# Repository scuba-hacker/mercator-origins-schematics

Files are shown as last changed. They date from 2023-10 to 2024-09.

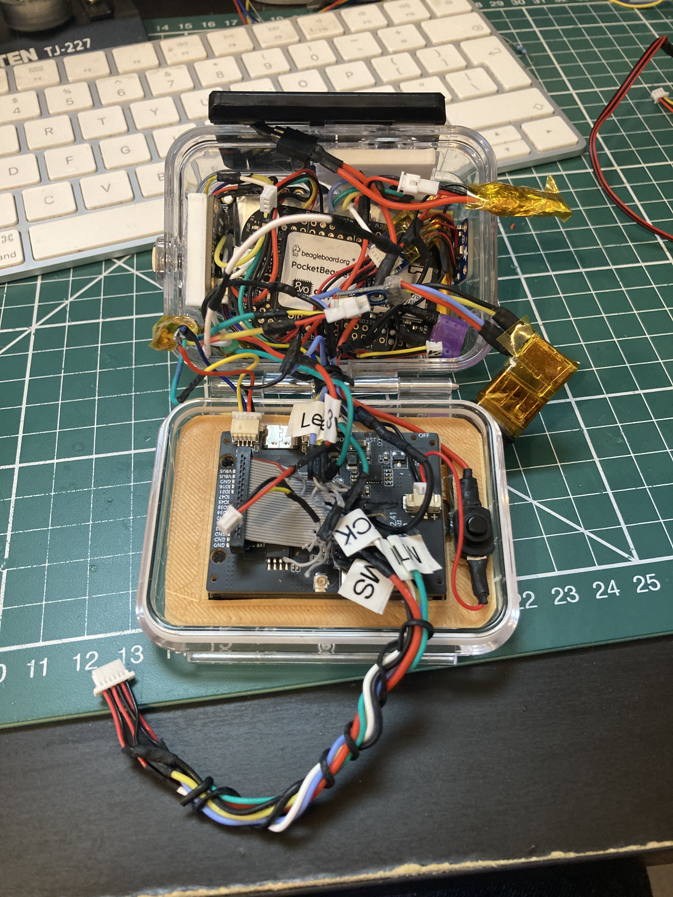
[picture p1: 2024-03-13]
Kicad/Oceanic/beagle and oceanic.jpg

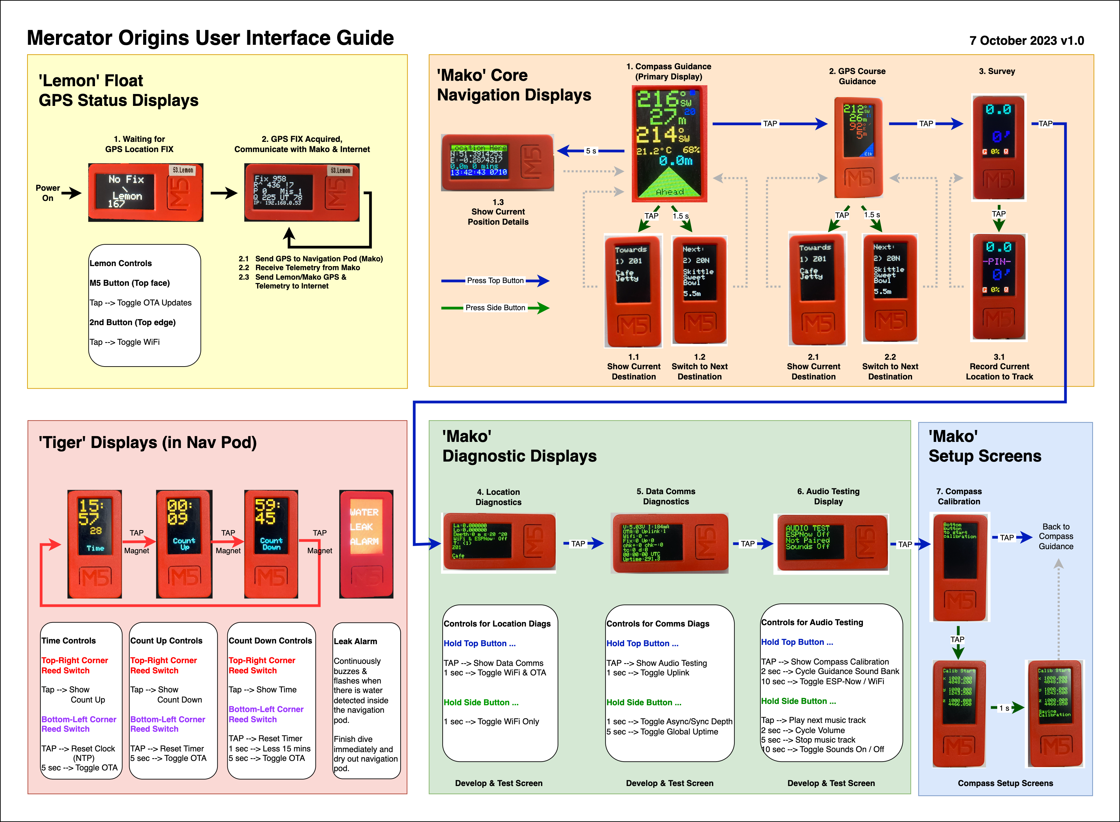
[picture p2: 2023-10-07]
DrawIO_Diagrams/Mercator Origins Displays and Controls.png

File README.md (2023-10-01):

# mercator-origins-schematics

3D Print files for button mounts. To follow: Console and Float schematics for drilling holes and sensor placement. Wiring harness schematics too.

GoPro_Side_Mount_image

Go_Pro_Top_Button_Mount_image

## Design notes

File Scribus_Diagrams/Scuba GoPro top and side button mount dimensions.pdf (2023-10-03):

# Top Button Mount, Top View

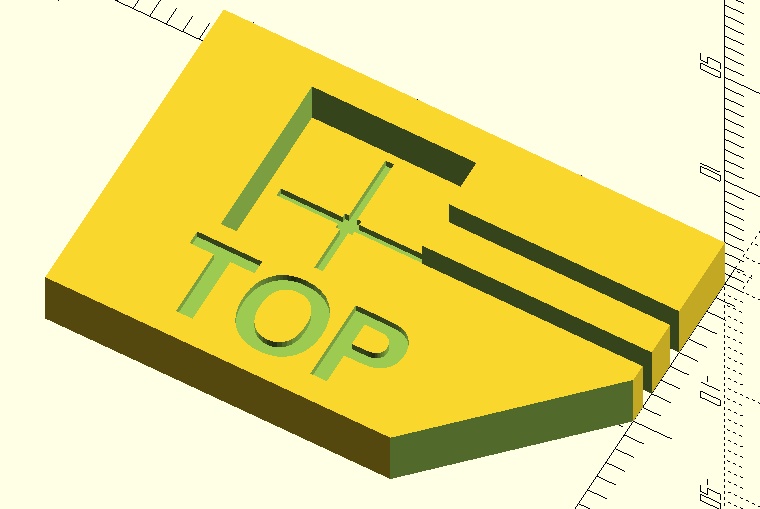
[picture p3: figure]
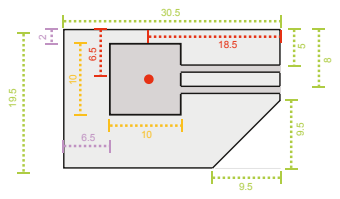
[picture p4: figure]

* All dimensions in millimetres.
* 3D print renders for illustration only.
* Light gray areas are 4mm thick.
* Dark gray areas are 1mm thick (bottom of mount)
* Wire channels are 1mm wide.
* Red spot is where to centre the microswitch button.

# Side Button Mount, Top View

Suggested build without 3D printer is to use a glued sandwich of two plastic window shims as follows:

1. Cut a 1mm thick shim to the overall outline of the mount and mark the centre point for the microswitch, with no internal cuts.
2. Cut a 3mm thick shim as per all cuts shown in the schematic omit the wire

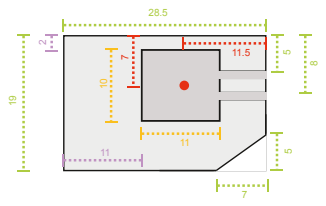
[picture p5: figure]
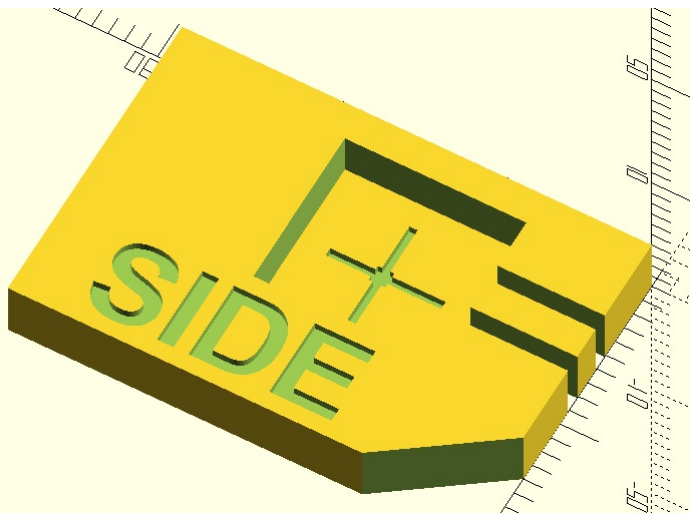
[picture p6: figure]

channel separator if you want. The cutout surrounding the microswitch just needs to be large enough to prevent the press button plunger from hitting edge of the cutout. Alternative to cutting is drilling a 10mm hole.

3. Glue the 1mm shim to the bottom of the 3mm shim.
4. Solder wires to your microswitch and glue the microswitch so that the button is positioned over the marked spot. Feed the wires out of the right side of the mount and glue wires to complete the build.

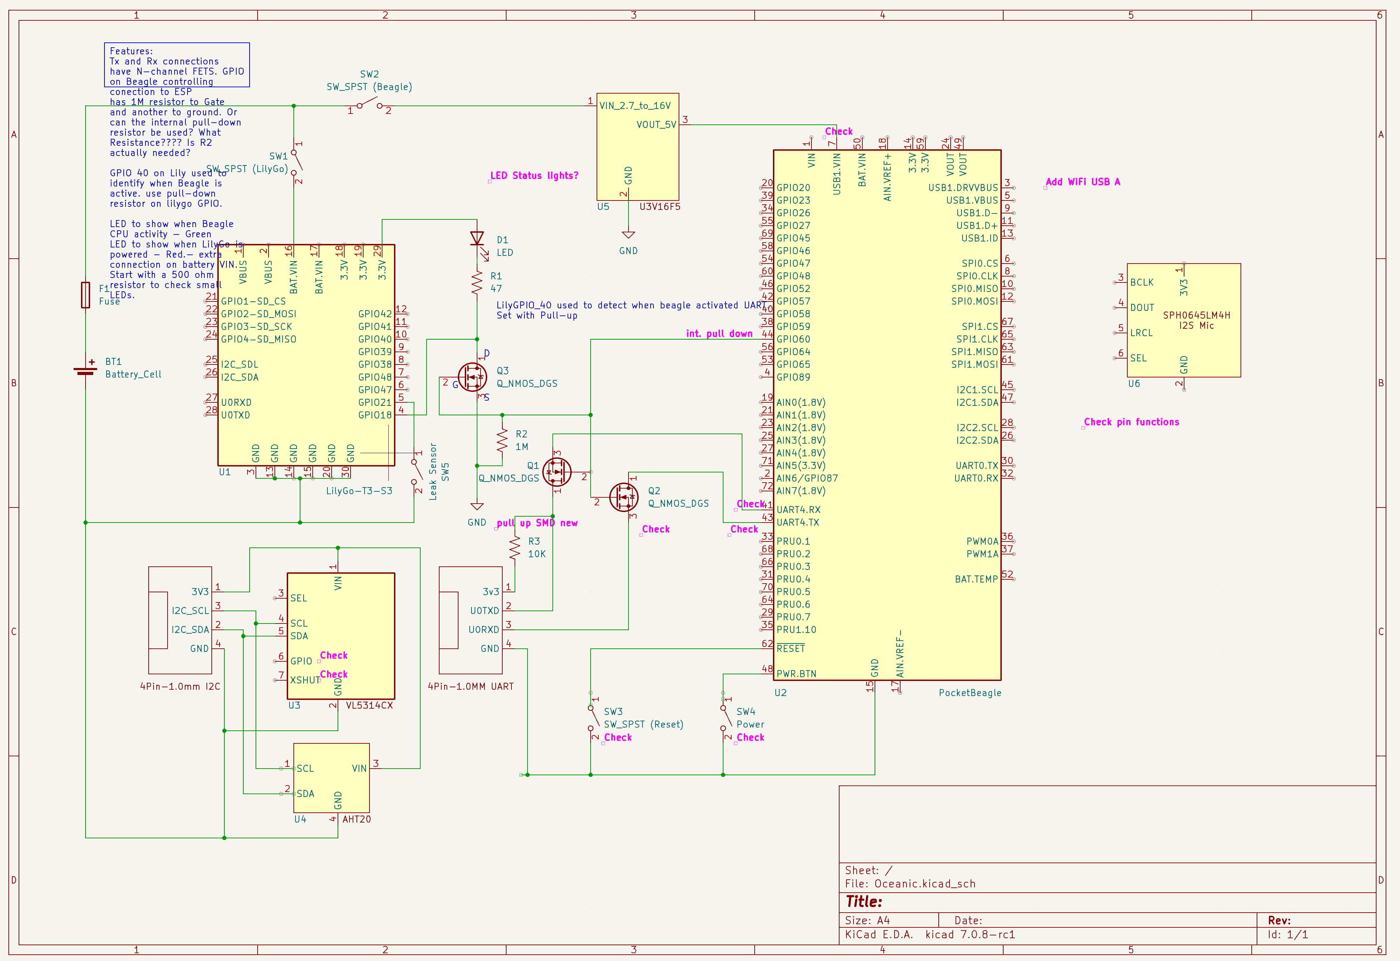
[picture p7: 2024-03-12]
Kicad/Oceanic/2024-03-12 1920 Oceanic Schematic Snapshot .png

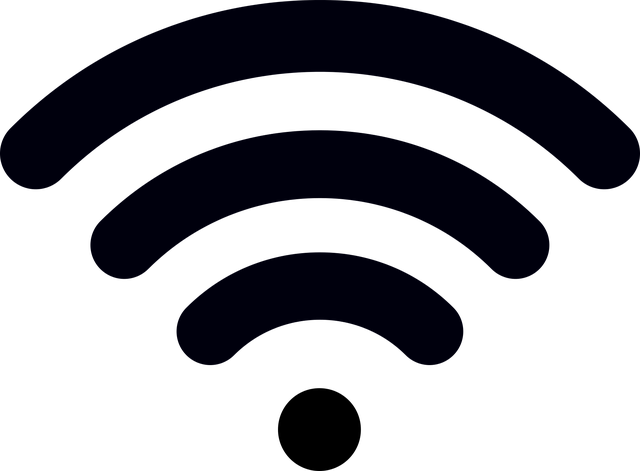
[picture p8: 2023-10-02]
Kicad/Audio-Pod-2/Images/wi-fi-2119225_640.png

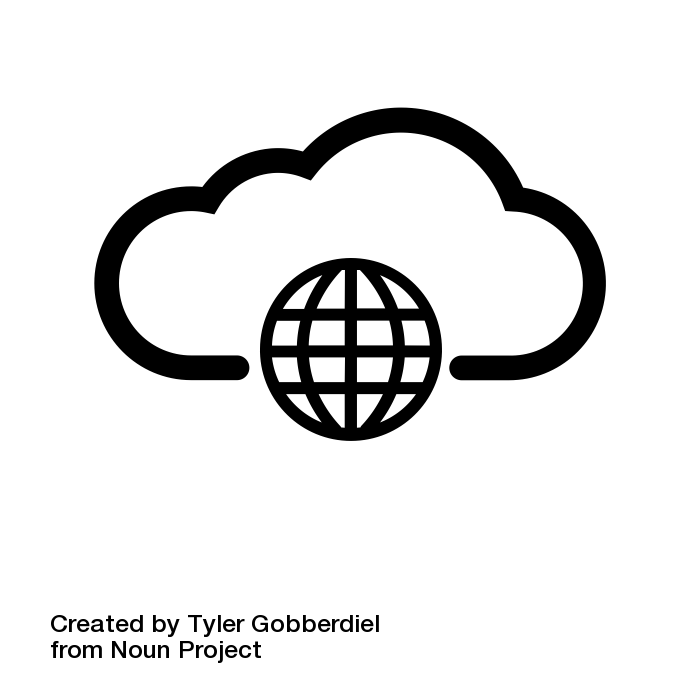
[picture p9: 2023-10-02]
Kicad/Lemon-GPS-Float/Images/noun-cloud-network-4059258.png

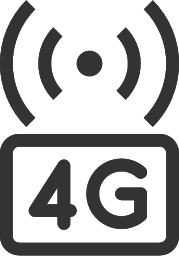
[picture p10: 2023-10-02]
Kicad/Lemon-GPS-Float/Images/4g.179x256.png

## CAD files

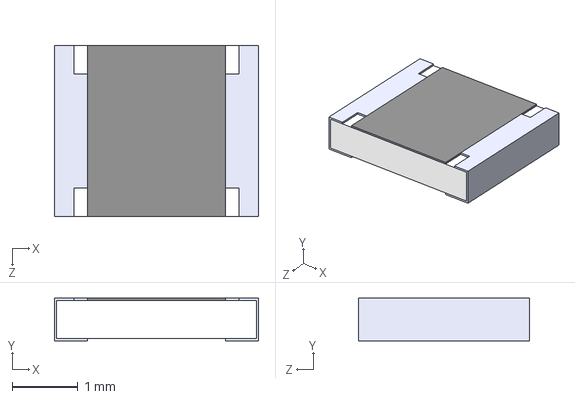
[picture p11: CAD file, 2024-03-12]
Kicad/Oceanic/KiCad Symbols/CRGCQ1210J1M0/CRGCQ1210J1M0.step
3.10 x 0.65 x 2.60 mm

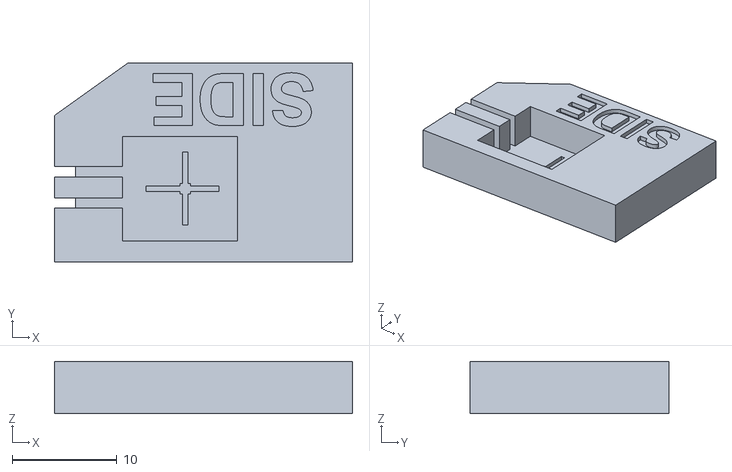
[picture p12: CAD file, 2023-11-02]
SCAD_3d_print/GoPro_Side_Mount.stl
28.5 x 19.0 x 5.00

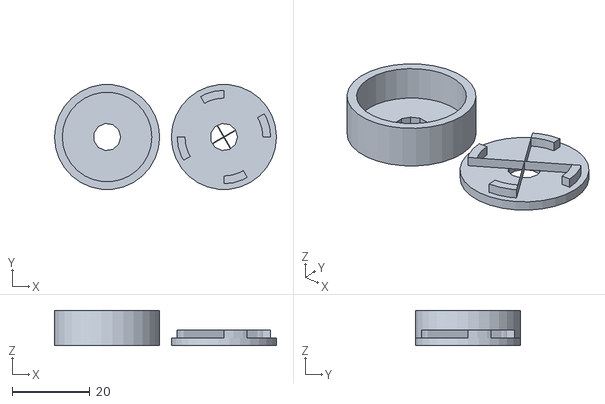
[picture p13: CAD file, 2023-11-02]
Torch Battery Shunt/torch_battery_shunt.stl
57.0 x 26.9 x 9.10

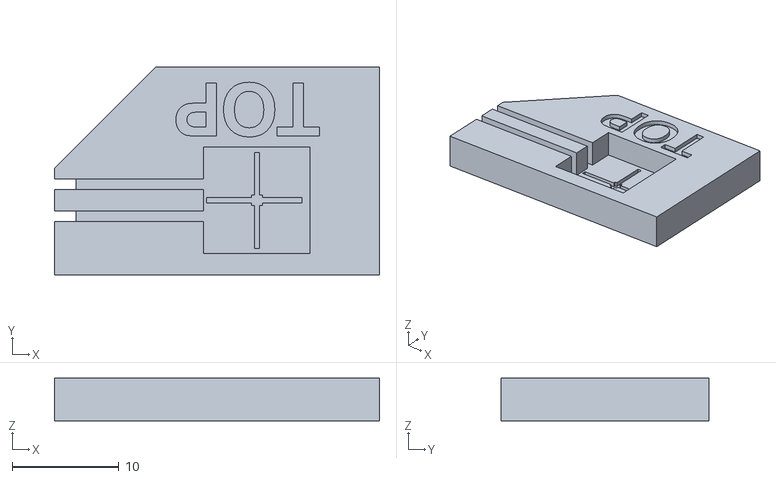
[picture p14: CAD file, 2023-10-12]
SCAD_3d_print/GoPro_Top_Button_Mount.stl
30.5 x 19.5 x 4.00

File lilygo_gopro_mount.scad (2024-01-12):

#include <BOSL2/std.scad>

$fs = 1;

// edge descriptors
// https://github.com/BelfrySCAD/BOSL2/wiki/attachments.scad#subsection-specifying-directions

interior_l = 73.8;
interior_w = 52.5;
interior_h = 6.2; // 6.2
interior_radius = 9;

med_l = 78.1;
med_w = 56.8;
med_h = 4.95;
med_radius = 11;

outer_l = 83.6;
outer_w = 61.6;
outer_h = 5.9;

outer_radius=13;

//insert_l = interior_l + 0.5;    // made .5mm longer than aperature      // ACTUAL PRINT WIDTH = 53.5 instead of 53 (correction is -0.5)
//insert_w = interior_w + 0.5;    // made .5mm wider than aperature       // ACTUAL PRINT LENGTH = 74.75 instead of 74.3 (correction is -0.45)

insert_l = interior_l + -0.5;    // corrected for next print 16 Jan (make exact interior length)
insert_w = interior_w + -0.45;   // corrected for next print 16 Jan (make exact interior width)


// 11/01 New measured cut width of insert: (needs removing from gopro case)
// 11/01  New measured cut length of insert: (needs removing from gopro case)

insert_h = 1.5;

screen_l = 56.2;   // measure       (11/01 measured again to be 56.2)   (11/01 measured inner ridge frame 55.73mm length)
screen_w = 43.9;   // measure       (11/01 measured again to be 43.9)   (11/01 measured inner ridth frame 43.35mm width)
screen_h = 1;

// screen has 3mm overlap on header short edge (currently 1.7mm), and 2mm overlap on lcd flex short edge (currently 1.85mm)
//screen has 2.35mm  overlap on antenna long edge and 2.7mm overlap on usb long edge


ridge_thickness = 1;

pcb_l = 52;
pcb_w = 39.2;
pcb_h = 1;

inner_shell_thickness = (med_l-interior_l)/2;

// insert

z_offset = 50;      // keeps the insert away from the gopro case in the view

ridge_pcb_cut_out_l = ridge_thickness*2;
ridge_pcb_cut_out_w = 22;
ridge_pcb_cut_out_h = insert_h;

ridge_pcb_cut_out_offset_w = 5.2;

ridge_usb_cut_out_l = 24;
ridge_usb_cut_out_w = ridge_thickness*2;
ridge_usb_cut_out_h = insert_h;

ridge_usb_cut_out_offset_l = 50 - ridge_usb_cut_out_l;

    
difference()
{
    difference()
    {
        // Insert to back screen, hole is sized to fit pcb attached to screen
        difference()       // (larger piece - smaller piece)
        {
            // the actual insert (square ring) that will be nanotaped down
            translate([0,0,z_offset])
                cuboid(
                    [insert_l,insert_w,insert_h], rounding=9,
                    edges=[RIGHT+BACK, RIGHT+FRONT, LEFT+BACK,LEFT+FRONT],
                    $fn=30,anchor=[-1,-1,-1]);
            
            // the hole in the insert
            translate([(insert_l-pcb_l-ridge_thickness)/2,(insert_w-pcb_w-ridge_thickness)/2,z_offset])
                cuboid(
                    [pcb_l+ridge_thickness,pcb_w+ridge_thickness,insert_h], rounding=0,
                    edges=[RIGHT+BACK, RIGHT+FRONT, LEFT+BACK,LEFT+FRONT],
                    $fn=30,anchor=[-1,-1,-1]);
                
        }
        
        // The notch added to the side of the insert hole
        // to account for the lcd pcb flex connector
        translate([(insert_l-screen_l)/2,(insert_w-screen_w)/2+ridge_pcb_cut_out_offset_w,z_offset])
            cuboid(
                [ridge_pcb_cut_out_l,ridge_pcb_cut_out_w,ridge_pcb_cut_out_h], rounding=0,
                edges=[RIGHT+BACK, RIGHT+FRONT, LEFT+BACK,LEFT+FRONT],
                $fn=30,anchor=[-1,-1,-1]);
    }

    // The notch added to the top of the insert hole
    // to account for the usb connector
    translate([(insert_l-screen_l)/2+ridge_usb_cut_out_offset_l,
               (insert_w-screen_w)/2,
               z_offset])
        cuboid(
            [ridge_usb_cut_out_l,ridge_usb_cut_out_w,ridge_usb_cut_out_h], rounding=0,
            edges=[RIGHT+BACK, RIGHT+FRONT, LEFT+BACK,LEFT+FRONT],
            $fn=30,anchor=[-1,-1,-1]);

}
/*
// Not required
// ****  error here is assuming the circuit board is centrally locally x/y  ****
//
// ridge to hold screen in place size of display, on back of insert
difference()       // (larger piece - smaller piece)
{
    // The outer square-cornered ridge under the insert which is hollow.
    translate([(insert_l-screen_l-ridge_thickness)/2,(insert_w-screen_w-ridge_thickness)/2,z_offset-screen_h])
        cuboid(
            [screen_l+ridge_thickness,screen_w+ridge_thickness,screen_h], rounding=0,
            edges=[RIGHT+BACK, RIGHT+FRONT, LEFT+BACK,LEFT+FRONT],
            $fn=30,anchor=[-1,-1,-1]);
        
    // The inner hole made in the ridge (this is exact screen dimensions)
    translate([(insert_l-screen_l)/2,(insert_w-screen_w)/2,z_offset-screen_h])
        cuboid(
            [screen_l,screen_w,screen_h], rounding=0,
            edges=[RIGHT+BACK, RIGHT+FRONT, LEFT+BACK,LEFT+FRONT],
            $fn=30,anchor=[-1,-1,-1]);
}
*/

/*
// not feasible
// peg for pulling the insert out of the gopro case
translate([5,38,z_offset+insert_h])
    cylinder(h=8,r=2);
*/
      
// Go pro back
/*
// top one, 
difference()
{
  
  translate([-inner_shell_thickness,-inner_shell_thickness,(interior_h-med_h)])
      cuboid(
        [med_l,med_w,med_h], rounding=med_radius,
        edges=[RIGHT+BACK, RIGHT+FRONT, LEFT+BACK,LEFT+FRONT],
        $fn=30,anchor=[-1,-1,-1]);
    
  translate([0,0,(interior_h-med_h)])
    cuboid(
        [interior_l,interior_w,med_h], rounding=interior_radius,
        edges=[RIGHT+BACK, RIGHT+FRONT, LEFT+BACK,LEFT+FRONT],
        $fn=30,anchor=[-1,-1,-1]);
  
}

difference()
{
    // outer part
    translate([-(outer_l-interior_l)/2,-(outer_w-interior_w)/2,-outer_h+(interior_h-med_h)])
    cuboid(
        [outer_l,outer_w,outer_h], rounding=med_radius,
        edges=[RIGHT+BACK, RIGHT+FRONT, LEFT+BACK,LEFT+FRONT],
        $fn=30,anchor=[-1,-1,-1]);

    // interior lower part
    translate([0,0,0])
    cuboid(
        [interior_l,interior_w,interior_h-med_h], rounding=interior_radius,
        edges=[RIGHT+BACK, RIGHT+FRONT, LEFT+BACK,LEFT+FRONT],
        $fn=30,anchor=[-1,-1,-1]);
    
}

*/

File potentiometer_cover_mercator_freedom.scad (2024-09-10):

// 4.6 mm x 4.6mm x 10mm high

#include <BOSL2/std.scad>

pot_width  = 9.6;
pot_length = 9.6;
pot_height = 10.0;

cover_thickness = 0.5;
tab_length = 19.0;

screw_hole_diameter = 0.7;
screw_offset = 11;

print_offset_x = 15;
print_offset_y = 15;
print_offset_z = 0;

anc=BOTTOM;

difference()       // pot sleeve
{
    cuboid([pot_width + cover_thickness * 2,pot_length + cover_thickness * 2, pot_height + cover_thickness],anchor=anc); // outer rect
    cuboid([pot_width + cover_thickness,pot_length + cover_thickness, pot_height],anchor=anc); // inner rect
}

translate ([print_offset_x,print_offset_y,print_offset_z])
    difference()
    {
        difference()
        {
                cuboid([tab_length, pot_length+2, cover_thickness], anchor=anc);       // bottom plate.
                cuboid([pot_width + cover_thickness*2, pot_length + cover_thickness*2, cover_thickness*3], anchor=anc);                    // hole in bottom plate.
        }
        
        translate ([tab_length - screw_offset,0,-cover_thickness])                  // left screw hole
            cylinder(h=cover_thickness*2,r=screw_hole_diameter,anchor=anc);

        translate ([-tab_length + screw_offset,0,-cover_thickness])
            cylinder(h=cover_thickness*2,r=screw_hole_diameter,anchor=anc);         // right screw hole    
    }

translate ([print_offset_x,print_offset_y,print_offset_z])
    difference()
    {
        difference()
        {
            cuboid([pot_width+cover_thickness*2 + 2, pot_length+cover_thickness*2 + 1, cover_thickness*3+2], anchor=anc);  // surround plate
            cuboid([pot_width+cover_thickness*2, pot_length+cover_thickness*2, cover_thickness*3+2], anchor=anc);      // hole in surround plate
        }
    }

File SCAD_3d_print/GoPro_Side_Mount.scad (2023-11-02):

// https://github.com/jon-gilbert/openscad_attachable_text3d/wiki/Installation
use <fontmetrics.scad>;

//font = "Liberation Sans Narrow:style=Bold";
font = "Arial:style=Bold";
font_size = 5;
h = ascender(font)-descender(font);

thickness = 5;
base = 1.0;
width = 28.5;
height = 19;
hole_width = 11.0;
hole_height = 10.0;
hole_NE_x = 6.5;
hole_NE_y = 2;

pin_x = 12;
pin_y = 6.5;
pin_width = 1.0;
pin_bredth = 1.0;
pin_depth = 0.5;

cut_out_N_x_offset=0;
cut_out_N_y_offset=height-5;
cut_out_S_x_offset=0;
cut_out_S_y_offset=height;
cut_out_E_x_offset=7;
cut_out_E_y_offset=height;

wire_notch_upper_N_y_offset=5.125;
wire_notch_lower_N_y_offset=8.125;
wire_notch_length=6.5;
wire_notch_base_length=2;


cross_hair_90_degree_length=7;
cross_hair_thickness = 0.5;

cross_hair_north_south_x_offset=pin_x+pin_width/4.0;

cross_hair_north_south_y_offset=pin_y+pin_bredth/2.0-cross_hair_90_degree_length/2.0;

cross_hair_east_west_x_offset=cross_hair_north_south_x_offset-cross_hair_90_degree_length/2.0;

cross_hair_east_west_y_offset=cross_hair_north_south_y_offset-pin_bredth/4.0+cross_hair_90_degree_length/2.0;

translate([0,0,1])

    difference()
    {
        cube([width,height,thickness-base]);
        
        translate ([hole_NE_x,hole_NE_y,0])
            cube([hole_width,hole_height,thickness-base]);

        linear_extrude(height = thickness, center = false)
            translate([0,0,thickness])
                polygon(points=[[cut_out_N_x_offset,cut_out_N_y_offset],[cut_out_S_x_offset,cut_out_S_y_offset],[cut_out_E_x_offset,cut_out_E_y_offset]]);

        translate ([0,wire_notch_upper_N_y_offset,0])
            cube([wire_notch_length,1,thickness]);

        translate ([0,wire_notch_lower_N_y_offset,0])
            cube([wire_notch_length,1,thickness]);

        rotate([180,180,0])
            translate([-25,-18,thickness-1.5])
                    linear_extrude(height=0.5) union() {  
                        translate([0,0]) drawText("SIDE", font=font, size=font_size);
                }
    }

    difference()
    {
        cube([width,height,base]);

        translate ([pin_x,pin_y,base-pin_depth])
            cube([pin_width,pin_bredth,pin_depth]);
        
        translate ([cross_hair_north_south_x_offset,cross_hair_north_south_y_offset,base-pin_depth])
            cube([cross_hair_thickness,cross_hair_90_degree_length,thickness-base]);

        translate ([cross_hair_east_west_x_offset,cross_hair_east_west_y_offset,base-pin_depth])
            cube([cross_hair_90_degree_length,cross_hair_thickness, thickness-base]);

        linear_extrude(height = thickness, center = false)
            translate([0,0,thickness])
                polygon(points=[[cut_out_N_x_offset,cut_out_N_y_offset],[cut_out_S_x_offset,cut_out_S_y_offset],[cut_out_E_x_offset,cut_out_E_y_offset]]);


        translate ([0,wire_notch_upper_N_y_offset,0])
            cube([wire_notch_base_length,1,thickness]);

        translate ([0,wire_notch_lower_N_y_offset,0])
            cube([wire_notch_base_length,1,thickness]);
    }

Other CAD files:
SCAD_3d_print/GoPro_Top_Button_Mount.scad
Torch Battery Shunt/torch_battery_shunt.scad

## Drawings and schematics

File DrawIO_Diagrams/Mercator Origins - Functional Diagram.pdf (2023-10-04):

## Navigation Pod Enclosure

## Floating Surface

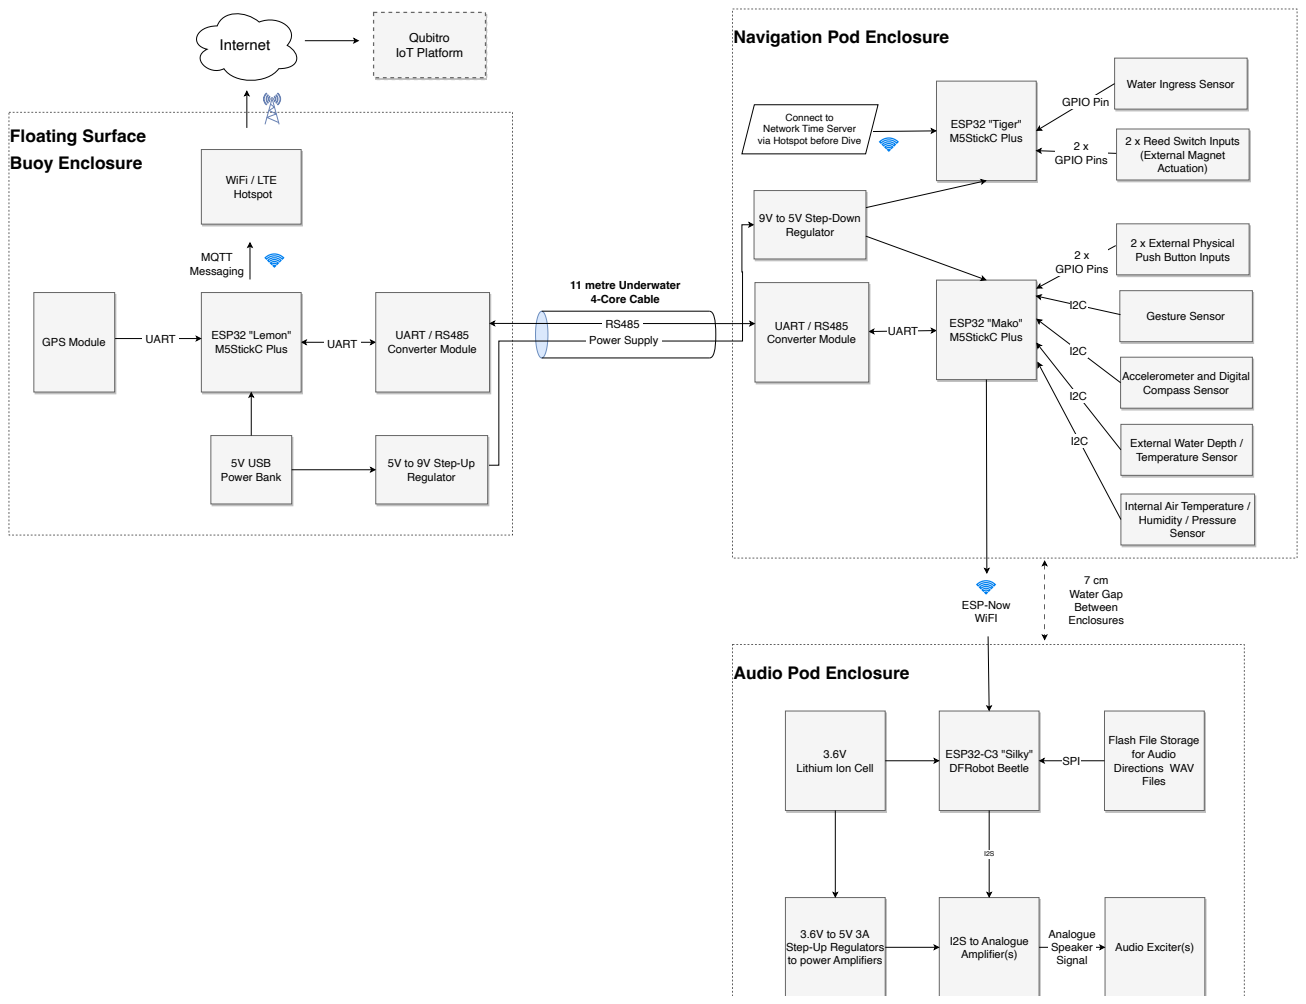
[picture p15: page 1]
Buoy Enclosure; Qubitro IoT Platform; UART ESP32 "Lemon" M5StickC Plus; UART / RS485; Converter Module GPS Module; UART; WiFi / LTE Hotspot; Internet; MQTT Messaging; ESP32 "Mako"; M5StickC Plus; UART / RS485 Converter Module; 5V USB Power Bank; Power Supply; 11 metre Underwater 4-Core Cable; Gesture Sensor; ESP32 "Tiger" M5StickC Plus; ESP32-C3 "Silky" DFRobot Beetle; I2S to Analogue; Amplifier(s); Audio Exciter(s); ESP-Now WiFI; 7 cm Water Gap Between Enclosures; GPIO Pin; SPI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

Water Ingress Sensor

Connect to
Network Time Server
via Hotspot before Dive

2 x Reed Switch Inputs
(External Magnet
Actuation)

9V to 5V Step-Down
Regulator

Accelerometer and Digital
Compass Sensor

External Water Depth /
Temperature Sensor

5V to 9V Step-Up

Internal Air Temperature /
Humidity / Pressure
Sensor

Audio Pod Enclosure

Flash File Storage
for Audio
Directions WAV
Files

Lithium Ion Cell

Step-Up Regulators
to power Amplifiers

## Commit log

2023-05-18 First commit of 3d Print SCAD files
    [GoPro_Side_Mount.scad, GoPro_Top_Button_Mount.scad]
2023-05-18 Move SCAD files to folder
    [GoPro_Side_Mount.scad, GoPro_Top_Button_Mount.scad]
2023-05-18 Upload diagrams, rename 3d print dir
    [GoPro_Side_Mount.scad, GoPro_Top_Button_Mount.scad]
2023-06-20 Update GoPro_Top_Button_Mount.scad
    width extended 2mm away from triangular cut-out (increase from 28 to 30)
    pin_x moved 2mm away from triangular cut-out (16 to 18)
    height reduced from 20.5 to 19.5mm
    and other changes commented in the script
    [GoPro_Top_Button_Mount.scad]
2023-06-20 Update GoPro_Side_Mount.scad
    Various fixes, including horizontal mirroring
    [GoPro_Side_Mount.scad]
2023-06-20 Update GoPro_Top_Button_Mount.scad
    whitespace
    [GoPro_Top_Button_Mount.scad]
2023-06-20 Update GoPro_Top_Button_Mount.scad
    add wire cut-outs
    [GoPro_Top_Button_Mount.scad]
2023-07-25 Update GoPro_Top_Button_Mount.scad
    Refinements
    [GoPro_Top_Button_Mount.scad]
2023-07-26 mirrored horizontally and 0.5mm width increase with associated hole and pin centre offsets applied
    [GoPro_Side_Mount.scad]
2023-08-01 Update GoPro_Side_Mount.scad
    moved crosshair and hole by 1mm and changed depth to 3.5mm
    [GoPro_Side_Mount.scad]
2023-09-27 Correct wire cut-outs to extend right instead of left
    [GoPro_Top_Button_Mount.scad]
2023-09-27 Add base notch to aid cable exit
    [GoPro_Side_Mount.scad]
2023-09-27 Added 3D SIDE label
    [GoPro_Side_Mount.scad]
2023-09-27 Added 3D TOP label
    [GoPro_Top_Button_Mount.scad]
2023-10-01 Tweak notch length
    [GoPro_Top_Button_Mount.scad]
2023-10-01 Schematic for Silky Audio Pod 2 - 3 speaker version
    [Audio-Pod-2.kicad_pcb, Audio-Pod-2.kicad_sch]
2023-10-01 Moved into Audio-Pod-2 Folder
    [Audio-Pod-2.kicad_pcb, Audio-Pod-2.kicad_sch]
2023-10-01 First commit of Lemon Float Schematics
    [Lemon-GPS-Float.kicad_pcb, Lemon-GPS-Float.kicad_sch]
2023-10-01 First commit of nav-pod
    [Nav-Pod.kicad_pcb, Nav-Pod.kicad_sch]
2023-10-02 Added Audio Pod 1 and updated with images and tweaks other schematics.
    [Audio-Pod-1.kicad_pcb, Audio-Pod-1.kicad_sch, Lemon-GPS-Float.kicad_sch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]
2023-10-02 Update scribus button mount schematics
2023-10-03 Refreshed schematics
2023-10-07 Corrected which corner to use for magnets
2023-10-12 Added 2 x 1 K Ohm biasing resistors to RS485 output and added STL files
    [GoPro_Side_Mount.stl, GoPro_Top_Button_Mount.stl, Lemon-GPS-Float.kicad_sch]
2023-10-12 updated to 5mm thickness
    [GoPro_Side_Mount.stl]
2023-11-09 Added real dimensions of new battery
    [torch_battery_shunt.scad]
2023-11-16 added latest test comments
    [torch_battery_shunt.scad]
2023-12-19 Mount for 2.4 inch LilyGo board
    [lilygo_gopro_mount.scad]
2024-01-12 Updated after first print
    [lilygo_gopro_mount.scad]
2024-03-12 Oceanic Schematic
    [CRGCQ1210J1M0.step, Oceanic.kicad_pcb, Oceanic.kicad_sch]
2026-10-30 Add Lantern schematic and cleaned up
